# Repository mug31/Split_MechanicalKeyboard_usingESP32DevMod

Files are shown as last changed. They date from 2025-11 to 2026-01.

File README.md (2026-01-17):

# Split_MechanicalKeyboard_usingESP32DevMod
My journey building a wireless split keyboard from scratch using ESP32 Dev Module. Includes custom firmware for matrix scanning and layer management.
## 📝 To-Do List
- [x] Protoyping the keyboard using breadboard n pushbutton
- [x] Connecting left-right side
- [x] Implement debouncing logic.
- [ ] Add battery level monitoring over BLE.
- [x] making the PCB file
- [ ] Design 3D printable case.

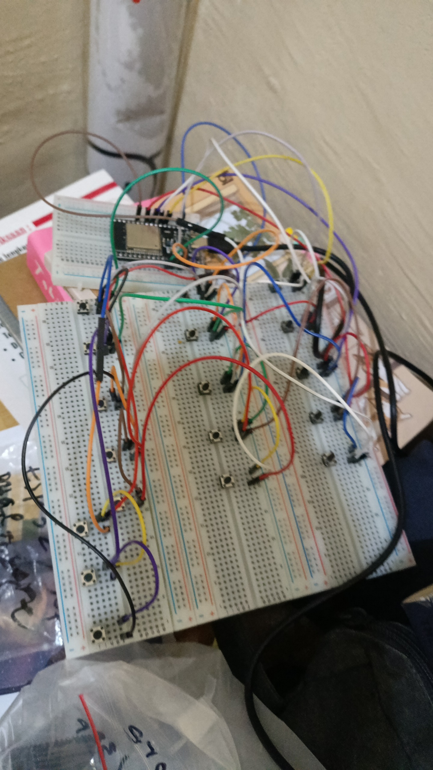
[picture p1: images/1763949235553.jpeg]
Tampilan Prototipe

*This is the prototype using breadboard-pushbutton, and it was using the matrix 4x5.*

## This is how the pcb looks like
i use KICAD to make this PCB, and for the footprint i use library from scotto keebs https://github.com/joe-scotto/scottokeebs/tree/main/Extras/ScottoKicad
| **Left side** | **Right side** |
|:---:|:---:|
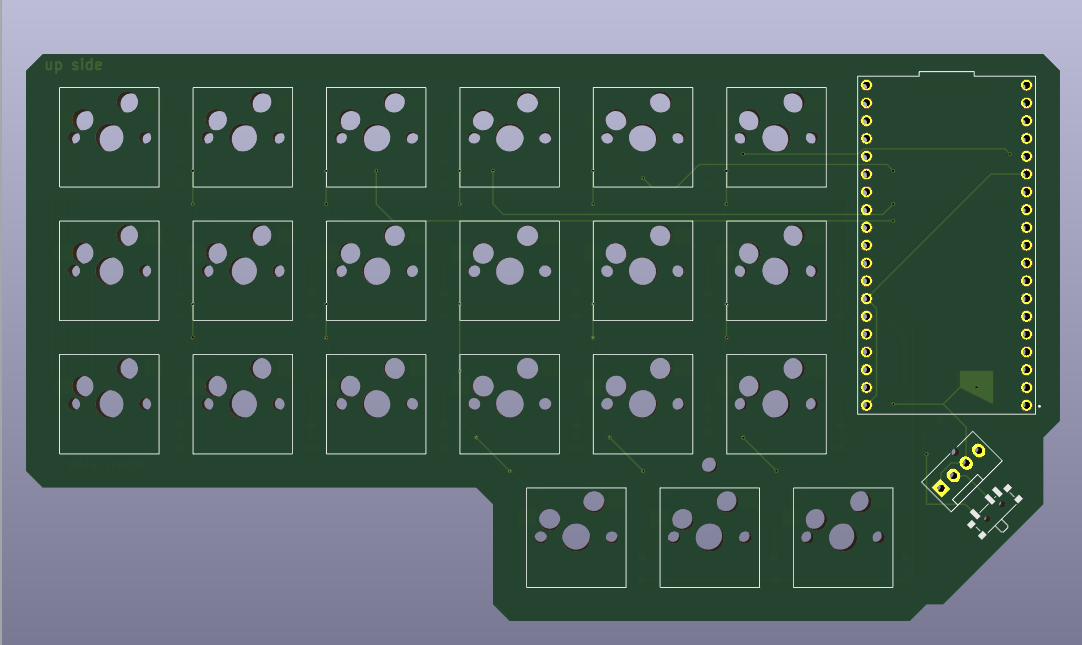
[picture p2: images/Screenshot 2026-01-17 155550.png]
Left
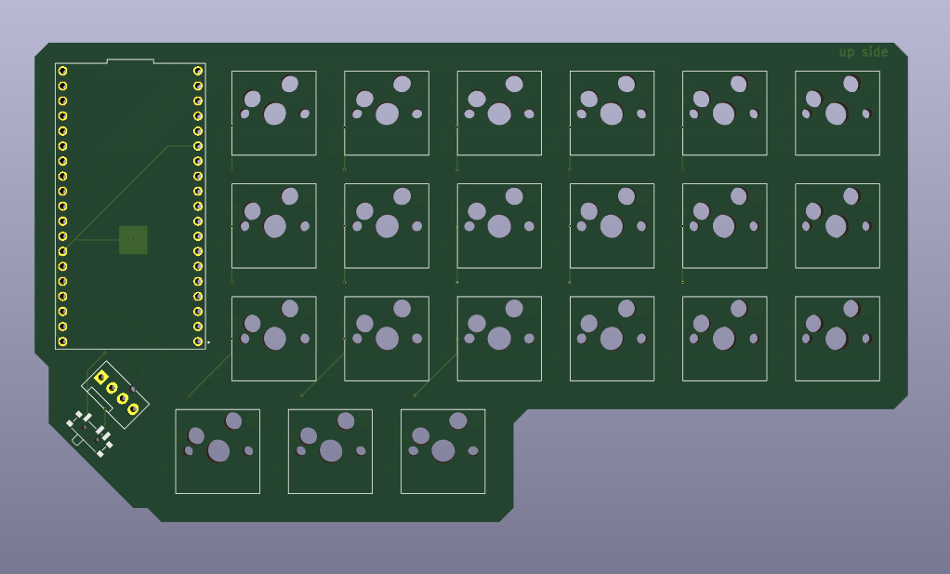
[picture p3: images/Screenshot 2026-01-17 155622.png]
Right
|  |  |

| **The Plate** |
|:---:|
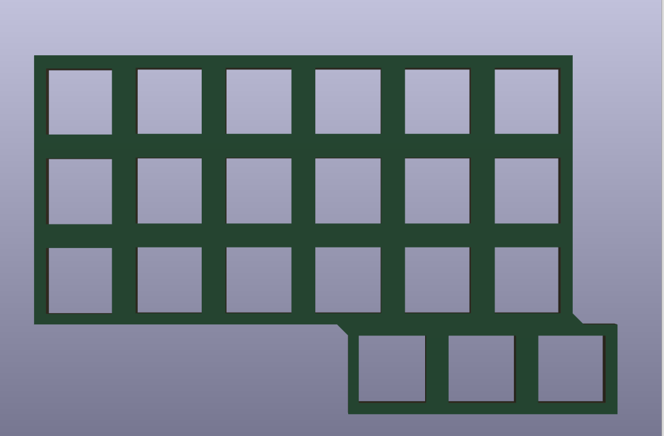
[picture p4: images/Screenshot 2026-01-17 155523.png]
Plate
|  |
| *Plate for the switch* |

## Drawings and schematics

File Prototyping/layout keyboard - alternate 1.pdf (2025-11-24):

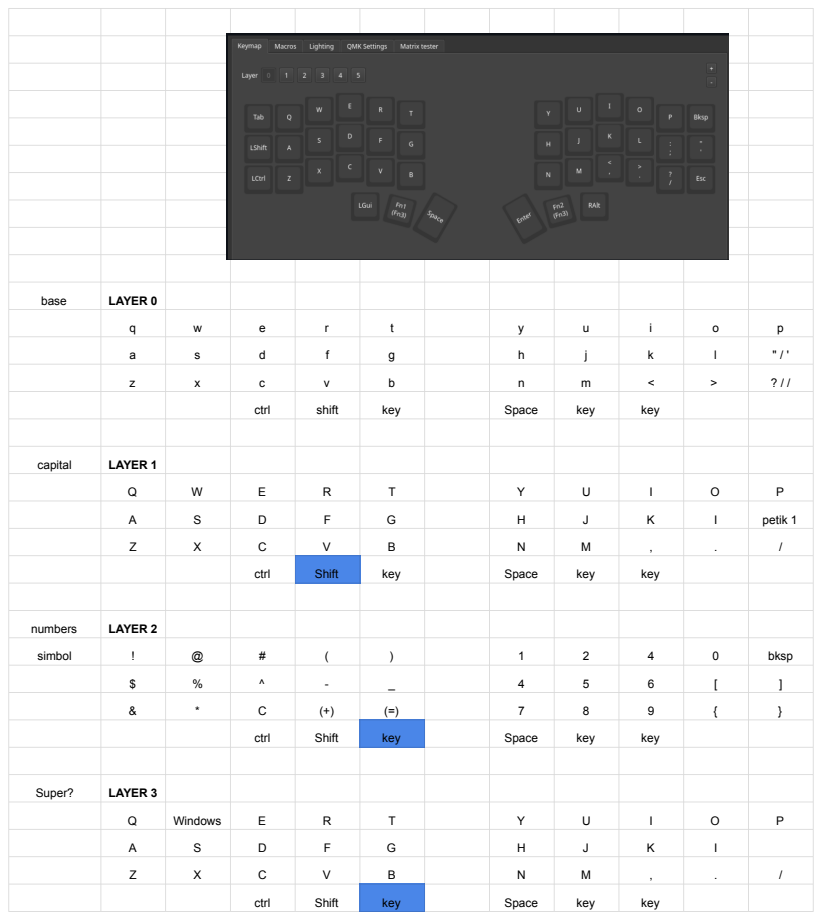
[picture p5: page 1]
base; LAYER 0; ctrl; shift; key; Space; capital; LAYER 1; petik 1; Shift; numbers; LAYER 2; simbol; bksp; Super?; LAYER 3; Windows

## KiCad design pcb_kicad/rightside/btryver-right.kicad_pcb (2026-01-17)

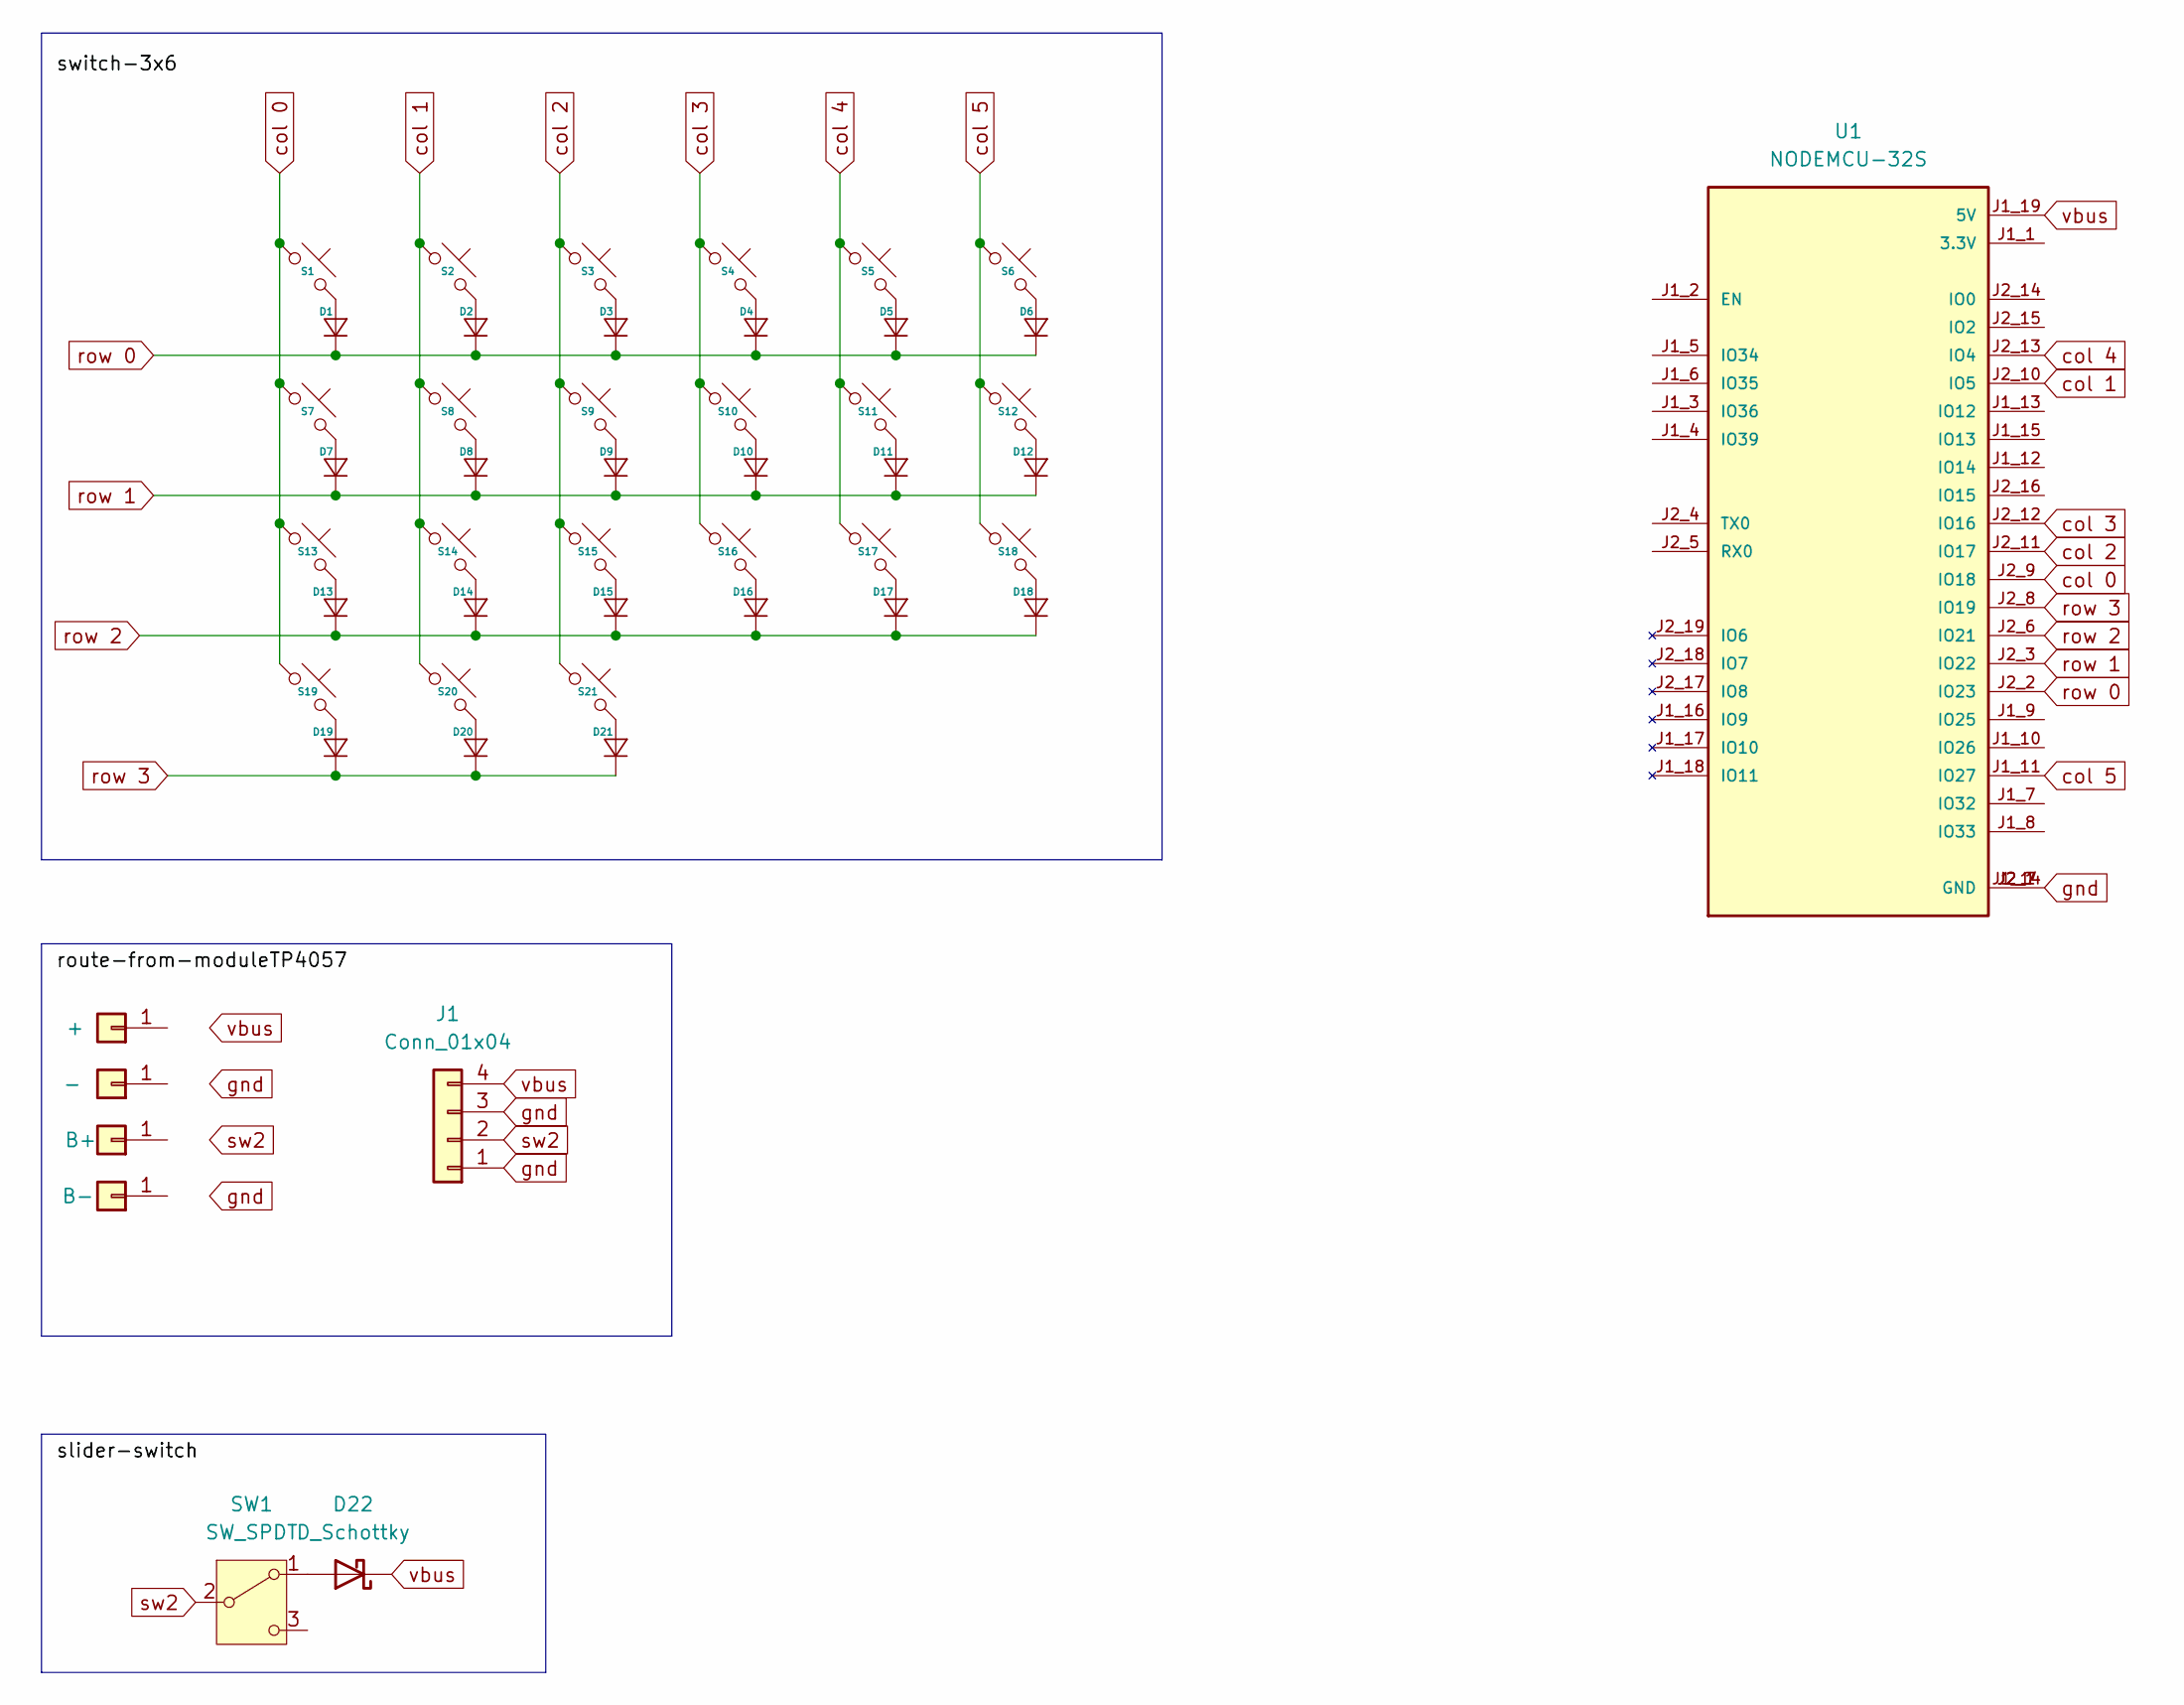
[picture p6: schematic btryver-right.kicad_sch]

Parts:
D1, D2, D3, D4, D5, D6, D7, D8, D9, D10, D11, D12, D13, D14, D15, D16, D17, D18, D19, D20, D21: Diode_SOD-123
D22: D_Schottky; D_SOD-123
J1: Conn_01x04; FanPinHeader_1x04_P2.54mm_Vertical
J3: B-; PinHeader_1x01_P2.54mm_Vertical
J5: -; PinHeader_1x01_P2.54mm_Vertical
J6: B+; PinHeader_1x01_P2.54mm_Vertical
J7: +; PinHeader_1x01_P2.54mm_Vertical
S1, S2, S3, S4, S5, S6, S7, S8, S9, S10, S11, S12, S13, S14, S15, S16, S17, S18, S19, S20, S21: Hotswap_MX_1.00u
SW1: SW_SPDT; SW_SPDT_PCM12
U1: NODEMCU-32S; MODULE_NODEMCU-32S; PARTREV V1

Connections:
unnamed: D1.2 (A), S1.2
unnamed: D2.2 (A), S2.2
unnamed: D3.2 (A), S3.2
unnamed: D4.2 (A), S4.2
unnamed: D5.2 (A), S5.2
unnamed: D6.2 (A), S6.2
unnamed: D7.2 (A), S7.2
unnamed: D8.2 (A), S8.2
unnamed: D9.2 (A), S9.2
unnamed: D10.2 (A), S10.2
unnamed: D11.2 (A), S11.2
unnamed: D12.2 (A), S12.2
unnamed: D13.2 (A), S13.2
unnamed: D14.2 (A), S14.2
unnamed: D15.2 (A), S15.2
unnamed: D16.2 (A), S16.2
unnamed: D17.2 (A), S17.2
unnamed: D18.2 (A), S18.2
unnamed: D19.2 (A), S19.2
unnamed: D20.2 (A), S20.2
unnamed: D21.2 (A), S21.2
unnamed: D22.2 (A), SW1.1 (A)
col 0: S1.1, S7.1, S13.1, S19.1, U1.J2_9 (IO18)
col 1: S2.1, S8.1, S14.1, S20.1, U1.J2_10 (IO5)
col 2: S3.1, S9.1, S15.1, S21.1, U1.J2_11 (IO17)
col 3: S4.1, S10.1, S16.1, U1.J2_12 (IO16)
col 4: S5.1, S11.1, S17.1, U1.J2_13 (IO4)
col 5: S6.1, S12.1, S18.1, U1.J1_11 (IO27)
gnd: J1.1, J1.3, U1.J1_14 (GND), U1.J2_1 (GND), U1.J2_7 (GND)
row 0: D1.1 (K), D2.1 (K), D3.1 (K), D4.1 (K), D5.1 (K), D6.1 (K), U1.J2_2 (IO23)
row 1: D7.1 (K), D8.1 (K), D9.1 (K), D10.1 (K), D11.1 (K), D12.1 (K), U1.J2_3 (IO22)
row 2: D13.1 (K), D14.1 (K), D15.1 (K), D16.1 (K), D17.1 (K), D18.1 (K), U1.J2_6 (IO21)
row 3: D19.1 (K), D20.1 (K), D21.1 (K), U1.J2_8 (IO19)
sw2: J1.2, SW1.2 (B)
vbus: D22.1 (K), J1.4, U1.J1_19 (5V)

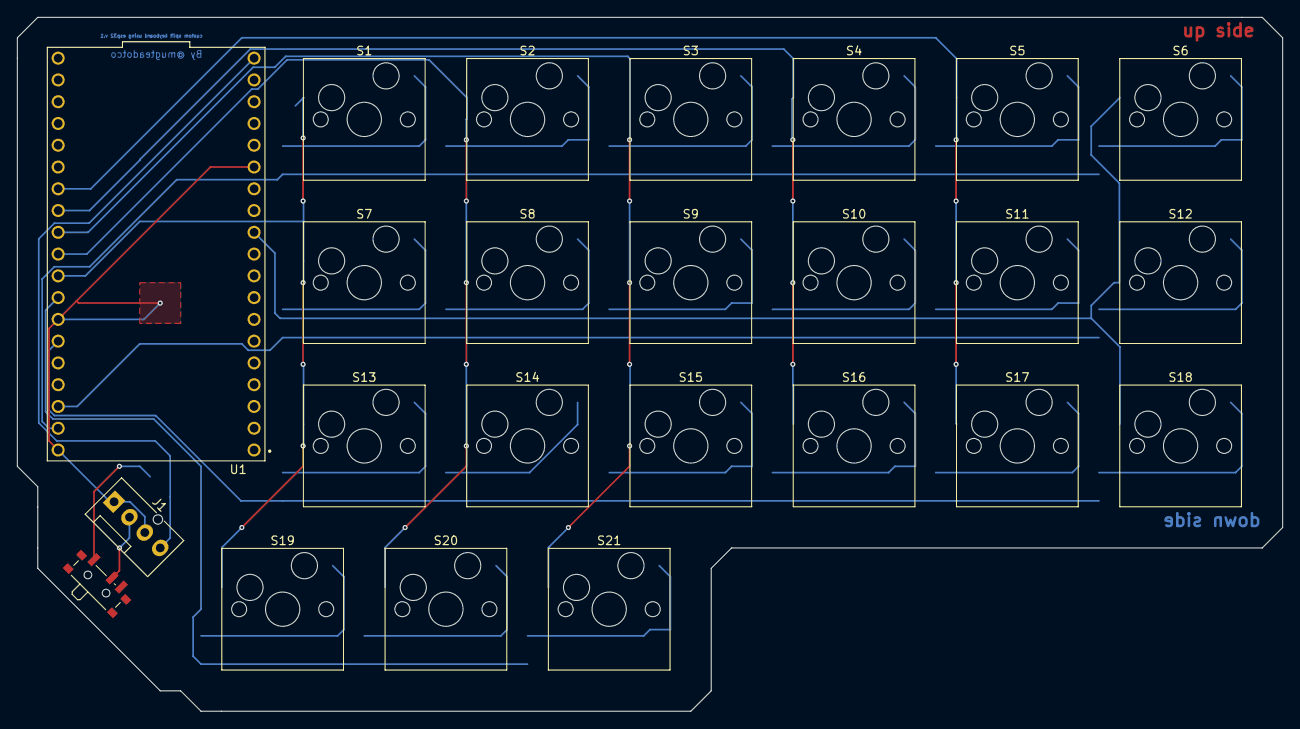
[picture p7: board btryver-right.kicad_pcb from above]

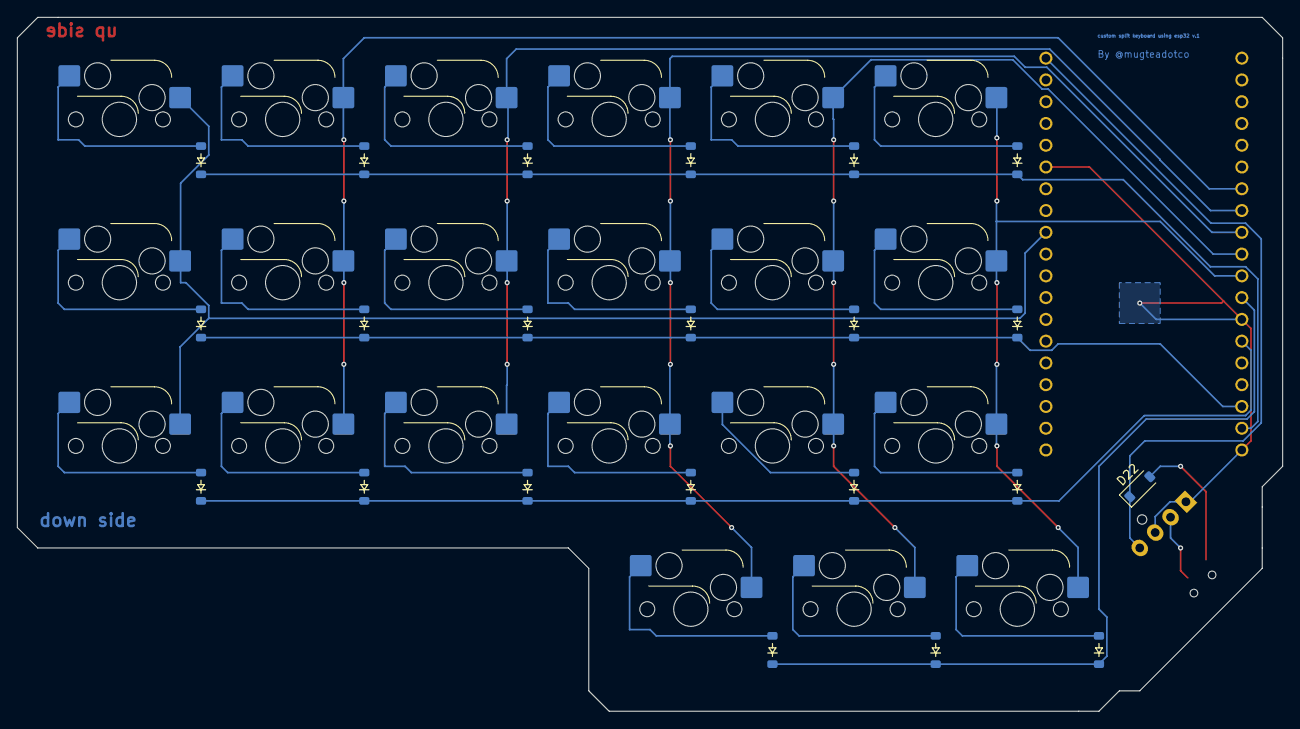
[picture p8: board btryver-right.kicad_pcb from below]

Board: 2 copper layers, 147.6 x 81.0 mm, 46 parts (22 on the bottom side), 35 nets.

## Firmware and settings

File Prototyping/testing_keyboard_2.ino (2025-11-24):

/*
 * Kode Bluetooth Keyboard Matrix V4
 * Matrix Fisik: 4 Baris (Rows) x 5 Kolom (Cols)
 * Logika Layer:
 * 1. Base (Layer 0)
 * 2. Shifted (Layer 1) - Diaktifkan oleh tombol R4/C2
 * 3. Fn/S-Key (Layer 2) - Diaktifkan oleh tombol R4/C3
 */

// 1. IMPORT LIBRARY-NYA
#include <BleKeyboard.h>

// Nama Bluetooth saat pairing
BleKeyboard bleKeyboard("Keyboard 4x5 Final");

// ==========================================
// 2. DEFINISI PETA KEYMAP & DIMENSI
// ==========================================

const int numRows = 4;
const int numCols = 5;

// --- LAYER 0 (Base Keys - Huruf Kecil) ---
// Note: Posisi Modifiers (R3/C1, R3/C2, R3/C3) akan di-handle secara terpisah.
char layer0_keymap[numRows][numCols] = {
  {'q', 'w', 'e', 'r', 't'}, // R1
  {'a', 's', 'd', 'f', 'g'}, // R2
  {'z', 'x', 'c', 'v', 'b'}, // R3
  {0, 0, 0, 0, 0}            // R4: Modifiers (Ctrl, Shift, S-Key), sisa kolom 0
};

// --- LAYER 2 (Fn/S-Key Layer - Symbols FIX!) ---
// Kita gunakan key code langsung. Layer ini aktif JIKA S-Key (Fn) ditekan.
// Mapping Sesuai permintaan Mukti: !@#()$%^-_&*C+=
const uint8_t layer2_keymap[numRows][numCols] = {
  {'!', '@', '#', '(', ')'}, // R1: ! @ # ( )
  {'$', '%', '^', '-', '_'}, // R2: $ % ^ - _ 
  {'&', '*', 'C', '+', '='}, // R3: & * C + =
  {0, 0, 0, 0, 0}            // R4: Modifiers (Diabaikan)
};

// ==========================================
// 3. DEFINISI POSISI MODIFIER & PIN
// ==========================================

// Posisi Tombol Modifiers di Matriks (Indeks dimulai dari 0)
// Modifiers ada di Baris 4 (Indeks 3)
const int MOD_ROW = 3;

// Posisi Tombol Modifier untuk Ctrl, Shift, dan S-Key
const int CTRL_COL = 0; // R4/C1 -> Ctrl
const int SHIFT_COL = 1; // R4/C2 -> Shift
const int FN_COL = 2; // R4/C3 -> S-Key/Fn

// --- PIN DEFINITION ---
const int rowPins[numRows] = {12, 13, 14, 15};    // GPIO 12, 13, 14, 15 (4 Baris)
const int colPins[numCols] = {16, 17, 18, 19, 21}; // GPIO 16, 17, 18, 19, 21 (5 Kolom)

bool lastKeyState[numRows][numCols];
bool isFnPressed = false; // State untuk S-Key (Fn)

// ==========================================
// SETUP
// ==========================================
void setup() {
  Serial.begin(115200);
  Serial.println("Mulai Uji Coba Keyboard BLE 4x5 (3 Layer Logics)...");

  // --- Setup Pin Baris (Row) sebagai INPUT_PULLUP ---
  for (int r = 0; r < numRows; r++) {
    pinMode(rowPins[r], INPUT_PULLUP);
  }
  
  // --- Setup Pin Kolom (Col) sebagai OUTPUT dan set HIGH ---
  for (int c = 0; c < numCols; c++) {
    pinMode(colPins[c], OUTPUT);
    digitalWrite(colPins[c], HIGH);
  }
  
  // Set semua status awal
  for (int r = 0; r < numRows; r++) {
    for (int c = 0; c < numCols; c++) {
      lastKeyState[r][c] = false;
    }
  }

  // Nyalain Keyboard Bluetooth-nya!
  bleKeyboard.begin();
  Serial.println("Keyboard Bluetooth siap di-pairing!");
}


// ==========================================
// LOOP (Logika Pemindaian Matriks)
// ==========================================
void loop() {
  if (bleKeyboard.isConnected()) {
    
    // Lakukan pemindaian matriks kolom demi kolom
    for (int c = 0; c < numCols; c++) {
      // Set kolom saat ini LOW (aktif)
      digitalWrite(colPins[c], LOW); 

      // Baca semua baris di kolom ini
      for (int r = 0; r < numRows; r++) {
        
        // Baca kondisi pin saat ini
        bool keyIsPressed = (digitalRead(rowPins[r]) == LOW);

        // Hanya proses jika ada perubahan state
        if (keyIsPressed != lastKeyState[r][c]) {
          
          // Cek apakah tombol yang sedang diproses ada di baris Modifiers (R4)
          bool isModifierRow = (r == MOD_ROW);

          if (keyIsPressed) {
            // === LOGIKA PRESS (DITEKAN) ===
            
            if (isModifierRow) {
              // Jika ini adalah baris Modifiers (R4)
              if (c == CTRL_COL) {
                // R4/C1: CTRL
                bleKeyboard.press(KEY_LEFT_CTRL);
                Serial.println("MODIFIER: CTRL Ditekan.");
              } else if (c == SHIFT_COL) {
                // R4/C2: SHIFT (Aktifkan Layer 1)
                bleKeyboard.press(KEY_LEFT_SHIFT);
                Serial.println("MODIFIER: SHIFT Ditekan (Aktivasi Layer Kapital).");
              } else if (c == FN_COL) {
                // R4/C3: S-KEY/FN (Aktifkan Layer 2)
                isFnPressed = true;
                Serial.println("MODIFIER: FN Ditekan (Aktivasi Layer 2/Symbols).");
              }
            } else {
              // Ini adalah tombol Huruf/Base (R1-R3)
              if (isFnPressed) {
                // Jika S-Key (Fn) sedang ditekan, kirim Layer 2 Key (Symbols)
                uint8_t key = layer2_keymap[r][c];
                bleKeyboard.press(key);
                Serial.print("Ditekan Layer 2 (FN/Symbol): ");
                Serial.println((char)key); // Cast to char untuk Serial.println
              } else {
                // Jika S-Key (Fn) TIDAK ditekan, kirim Layer 0 Key (Huruf)
                // Jika tombol Shift (R4/C2) ditekan, otomatis menjadi kapital.
                char key = layer0_keymap[r][c];
                bleKeyboard.press(key);
                Serial.print("Ditekan Layer 0/1: ");
                Serial.println(key);
              }
            }
          } 
          else {
            // === LOGIKA RELEASE (DILEPAS) ===
            
            if (isModifierRow) {
              // Jika ini adalah baris Modifiers (R4)
              if (c == CTRL_COL) {
                // R4/C1: CTRL
                bleKeyboard.release(KEY_LEFT_CTRL);
                Serial.println("MODIFIER: CTRL Dilepas.");
              } else if (c == SHIFT_COL) {
                // R4/C2: SHIFT
                bleKeyboard.release(KEY_LEFT_SHIFT);
                Serial.println("MODIFIER: SHIFT Dilepas.");
              } else if (c == FN_COL) {
                // R4/C3: S-KEY/FN
                isFnPressed = false;
                Serial.println("MODIFIER: FN Dilepas (Kembali ke Layer 0/1).");
              }
            } else {
              // Ini adalah tombol Huruf/Base (R1-R3)
              if (isFnPressed) {
                // Lepas Layer 2 Key (Symbols)
                uint8_t key = layer2_keymap[r][c];
                bleKeyboard.release(key);
              } else {
                // Lepas Layer 0/1 Key
                char key = layer0_keymap[r][c];
                bleKeyboard.release(key);
              }
              Serial.println("...Tombol Dilepas.");
            }
          }
          
          // Simpan state terakhir
          lastKeyState[r][c] = keyIsPressed; 
        }
      }
      
      // Setelah membaca semua baris, set kolom kembali HIGH (nonaktif)
      digitalWrite(colPins[c], HIGH); 
    }
  }
  delay(10); // Debounce delay
}

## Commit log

2025-11-24 Add files via upload
    this how the prototype look by using breadboard-pushbutton. And also the esp32 that i use
2025-11-24 Update README with prototype details
    Added a note about the prototype using a breadboard and pushbutton.
2026-01-17 Update README with completed PCB file task
2026-01-17 Update README with PCB images and prototype details
    Added images and descriptions of the PCB and prototype.
2026-01-17 Revise PCB section with KICAD info and images
    Updated PCB section with KICAD details and organized images in a table format.
2026-01-17 Create Pcb_kicad
2026-01-17 Create kicad_pcb
